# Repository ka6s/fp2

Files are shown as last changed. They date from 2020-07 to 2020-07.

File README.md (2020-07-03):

# fp2
PiHPSDR Controller v2 based on LA2NI design

This design is un-abashedly copied from LA2NI's Controller2 design.

It is SIMPLIFIED in that it doesn't have an power supplies or On/Off buttons.  It takes 5V power
and sends it to the Raspberry Pi mounted on the controller.

The design uses the classic 7 inch Raspberry Pi LCD touch panel.  

The rotary encoders are NOT cheap.  It uses 1 of the HRPG-ASCA-54F 54 PPR encoders, and 4 Elma E37 dual shaft
encoders.  Each of these is on the order of $30.  Ordering information is in fp2_BOM.xls

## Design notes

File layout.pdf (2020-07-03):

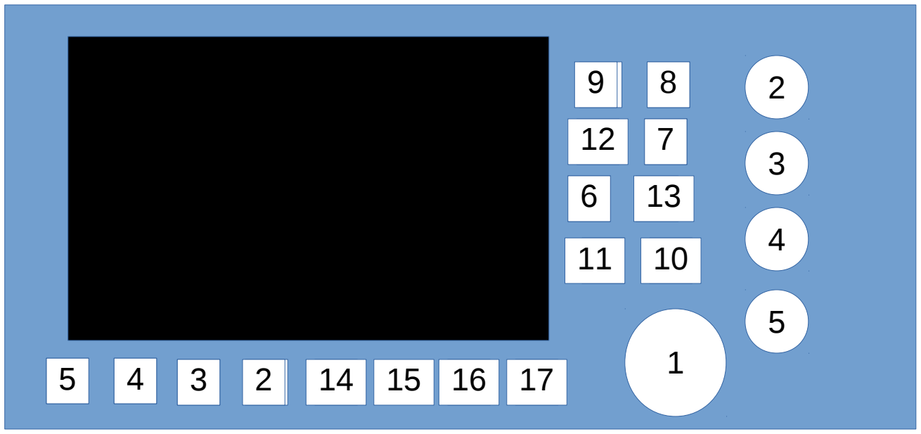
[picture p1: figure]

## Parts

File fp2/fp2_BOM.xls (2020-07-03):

Reference | Quantity | Mouser | Value
J2 | 1 | 485-2223 | Adafruit GPIO Stacking Header 2x20 – Note 3
RN1;RN3;RN2;RN5;RN4 | 5 | 652-4610H-1LF-10K | 10K Resistor Network
U1 | 1 | 579-MCP23017-E/SP | MCP23017_SO
C3 | 1 | 810-C2012X7S1E106125 | 10uF 0805
C2 | 1 | 963-TMF212B7103MGHT | 0.01uF
SW9;SW8;SW7;SW6;SW5;SW4;SW3;SW2;SW17;SW16;SW15;SW14;SW13;SW12;SW11;SW10 | 16 | 375-LS-00002 ( 2 sets) | SPST – 12 mm x12 mm – Note 2
J4 | 1 | 571-1029765 | 1x5 Berg Post
ENC1 | 1 | 630-HRPG-ASCA-54F | HRPG-ASCA#54A
J3 | 1 | 571-1029765 | Conn_01x03
U2;U3 | 16 | 72-AY2103M61Y5VS63L0 | 0.01uF ARRAY – Note 4
ENC2;ENC3;ENC4;ENC5 | 4 | See Note 1 Below | ELMA E37 Dual Shaft Encoder – VT3880-1
C1 | 1 | 667-EEH-ZK1V221UP | 220uF
J1 | 1 | 806-KLDHCX-0202-AC-1 | DC Power Connector
Note 1: Order ELMA E37 directly from Elma |  | `
https://www.elma.com/en/products/rotary-switches/rotary-switching-products/product-pages/type-e37-detail/
I suggest the companion knobs as well.
In the US I used the Western Sales office which happens to be in my home town.
Elma Electronics, 44350 S. Grimmer Blvd, Fremont, CA 510-656-3400.
Note: For the SPST Switches I bought a collection from Amazon that had varying heights.
https://www.amazon.com/Hilitchi-200-Pcs-Tactile-Momentary-Assortment/dp/B071YPZ4G1
Note 3: Mount stand-offs first, then connect J2 to the Raspberry Pi, and THEN insert into the board
Screw the Raspberry Pi down to the board to adjust the height of J2 – THEN solder J2 in.
Note 4: – 8 individual Disc Ceramics soldered into DIP socket location

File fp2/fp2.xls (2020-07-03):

Reference | Quantity | Identifier | Package | Value | Tolerance | Voltage | Current | Power | PN
H2;H3;H4;H5;H6;H7;H8;H1;H10;H11;H12;H13;H14;H15;H16;H9 | 16 |  |  | MountingHole_Pad
J2 | 1 |  |  | Conn_02x20_Odd_Even
ENC3;ENC2;ENC4;ENC5 | 4 |  |  | Dual_Rotary_Encoder_Switch
RN1;RN3;RN2;RN5;RN4 | 5 |  |  | 10K
U1 | 1 |  |  | MCP23017_SO
C3 | 1 |  |  | 10uF
C2 | 1 |  |  | 0.01uF
SW9;SW8;SW7;SW6;SW5;SW4;SW3;SW2;SW17;SW16;SW15;SW14;SW13;SW12;SW11;SW10 | 16 |  |  | SW_SPST
J1 | 1 |  |  | Barrel_Jack_MountingPin
J3 | 1 |  |  | Conn_01x05_Male
C1 | 1 |  |  | 220uF

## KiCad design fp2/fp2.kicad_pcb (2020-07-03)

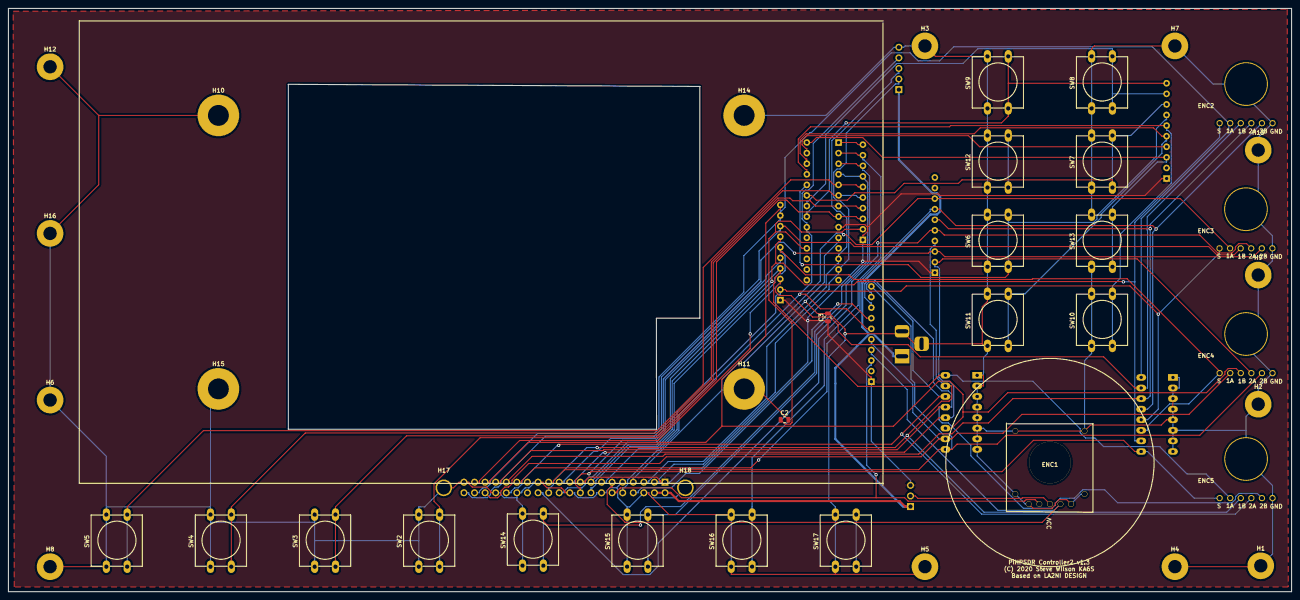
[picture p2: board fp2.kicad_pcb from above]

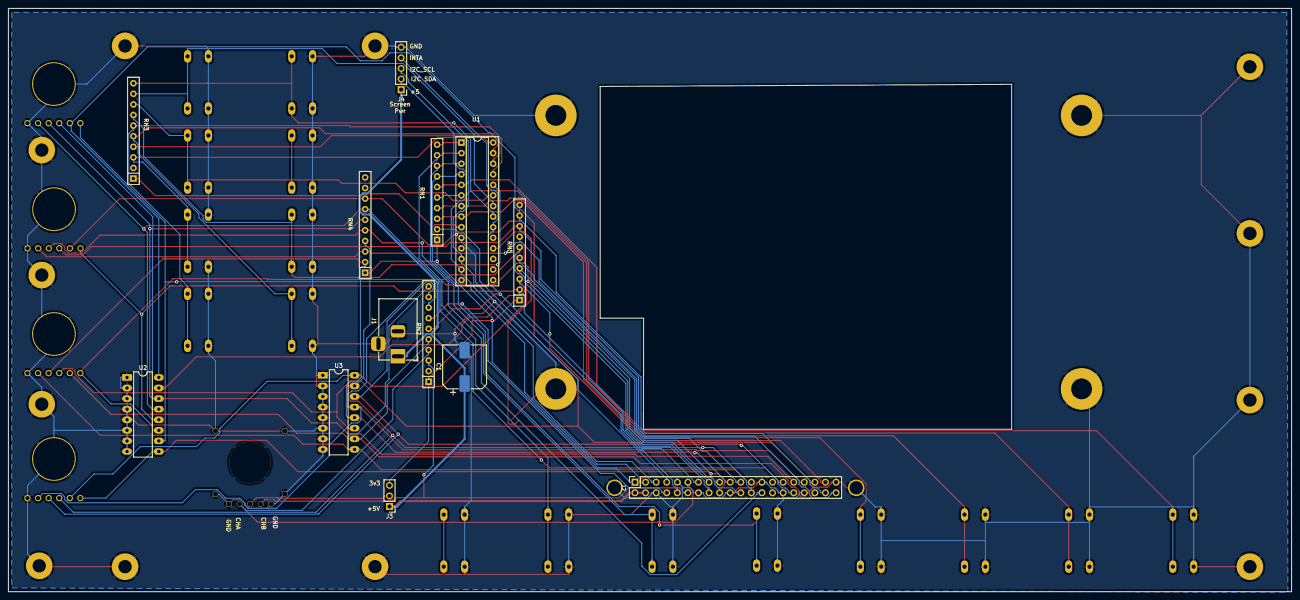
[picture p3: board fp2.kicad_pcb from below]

Board: 2 copper layers, 308.0 x 140.0 mm, 54 parts (13 on the bottom side), 47 nets.

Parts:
C1: 220uF; CP_Elec_10x10
C2: 0.01uF; C_0805_2012Metric
C3: 10uF; C_0805_2012Metric
ENC1: Rotary_Encoder_HRPG
ENC2, ENC3, ENC4, ENC5: rotary_encoder_elma37a; ELMA_E37A
H1, H2, H3, H4, H5, H6, H7, H8, H9, H12, H13, H16, H17, H18: MountingHole_Pad; MountingHole_3.2mm_M3_Pad
H10, H11, H14, H15: MountingHole_Pad; MountingHole_5mm_Pad
J1: Barrel_Jack_MountingPin; BarrelJack_Horizontal
J2: Conn_02x20_Odd_Even; PinSocket_2x20_P2.54mm_Vertical
J3: Conn_01x03; PinHeader_1x03_P2.54mm_Vertical
J4: Conn_01x05; PinHeader_1x05_P2.54mm_Vertical
RN1, RN2, RN3, RN4, RN5: 10K; R_Array_SIP10
SW2, SW3, SW4, SW5, SW6, SW7, SW8, SW9, SW10, SW11, SW12, SW13, SW14, SW15, SW16, SW17: SW_SPST; SW_PUSH-12mm
U1: MCP23017_SO; DIP-28_W7.62mm_Socket
U2, U3: 0.01uF ARRAY; CAP_ARRAY_16

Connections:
/encoder/3V3: C3.1, J2.1, J2.17, J3.3, RN1.1, RN2.1, RN3.1, RN4.1, RN5.1, U1.9
/encoder/5V: C1.1, J1.1, J2.2, J2.4, J3.1, J4.1
/encoder/GBP0: RN1.10, U1.1
/encoder/GPA0: RN3.10, SW9.2, U1.21
/encoder/GPA1: RN3.9, SW8.2, U1.22
/encoder/GPA2: RN3.8, SW7.2, U1.23
/encoder/GPA3: RN3.7, SW6.2, U1.24
/encoder/GPA4: RN3.6, SW10.2, U1.25
/encoder/GPA5: RN3.5, SW11.2, U1.26
/encoder/GPA6': RN3.4, U1.27
/encoder/GPA7: RN3.3, SW13.2, U1.28
/encoder/GPB1: RN1.9, SW16.2, U1.2
/encoder/GPB2: RN1.8, SW15.2, U1.3
/encoder/GPB3: RN1.7, SW14.2, U1.4
/encoder/GPB4: RN1.6, SW5.2, U1.5
/encoder/GPB5: RN1.5, SW4.2, U1.6
/encoder/GPB6: RN1.4, SW3.2, U1.7
/encoder/GPB7: RN1.3, SW2.2, U1.8
/encoder/GPIO4: ENC3.2, J2.7, RN4.8
/encoder/GPIO5: ENC2.5, J2.29, RN4.7, U2.13
/encoder/GPIO6: ENC2.4, J2.31, RN4.6, U2.14
/encoder/GPIO7: ENC3.4, J2.26, RN4.5
/encoder/GPIO8: ENC5.3, J2.24, RN4.4, U3.15
/encoder/GPIO9: ENC3.5, J2.21, RN4.3
/encoder/GPIO10: ENC4.4, J2.19, RN4.2, U3.12
/encoder/GPIO11: ENC4.5, J2.23, RN2.10, U3.9
/encoder/GPIO12: ENC5.4, J2.32, RN2.9, U3.14
/encoder/GPIO13: ENC5.5, J2.33, RN2.8, U3.13
/encoder/GPIO14: J2.8, RN2.7
/encoder/GPIO15: J2.10, J4.4, RN2.6, U1.20
/encoder/GPIO16: ENC4.2, J2.36, RN2.5, U3.10
/encoder/GPIO17: ENC1.2, J2.11, RN2.4
/encoder/GPIO18: ENC1.4, J2.12, RN2.3
/encoder/GPIO19: ENC4.3, J2.35, RN5.10, U3.11
/encoder/GPIO20: ENC2.2, J2.38, RN5.9, U2.16
/encoder/GPIO21: ENC3.3, J2.40, RN5.8
/encoder/GPIO22: ENC2.1, J2.15, RN5.7, U2.10
/encoder/GPIO23: ENC4.1, J2.16, RN5.6, U2.11
/encoder/GPIO24: ENC5.1, J2.18, RN5.5, U2.9
/encoder/GPIO25: ENC5.2, J2.22, RN5.4, U3.16
/encoder/GPIO26: ENC2.3, J2.37, RN5.3, U2.15
/encoder/GPIO27: ENC3.1, J2.13, RN5.2, U2.12
/encoder/I2C_SCL: J2.5, J4.3, U1.12
/encoder/I2C_SDA: J2.3, J4.2, U1.13
GND: C1.2, C2.2, C3.2, ENC1.1, ENC1.5, ENC2.6, ENC3.6, ENC4.6, ENC5.6, H1.1, H2.1, H3.1, H4.1, H5.1, H6.1, H7.1, H8.1, H9.1, H10.1, H11.1, H12.1, H13.1, H14.1, H15.1, H16.1, H17.1, H18.1, J1.2, J1.MP, J2.6, J2.9, J2.14, J2.20, J2.25, J2.30, J2.34, J2.39, J4.5, SW2.1, SW3.1, SW4.1, SW5.1, SW6.1, SW7.1, SW8.1, SW9.1, SW10.1, SW11.1, SW12.1, SW13.1, SW14.1, SW15.1, SW16.1, SW17.1, U1.10, U2.1, U2.2, U2.3, U2.4, U2.5, U2.6, U2.7, U2.8, U3.1, U3.2, U3.3, U3.4, U3.5, U3.6, U3.7, U3.8
unnamed: C2.1, RN1.2, U1.18
unnamed: ENC1.3, J3.2

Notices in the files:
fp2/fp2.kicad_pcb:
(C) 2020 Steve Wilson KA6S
